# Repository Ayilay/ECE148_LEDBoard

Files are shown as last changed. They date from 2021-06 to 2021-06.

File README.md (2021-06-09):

# ECE148 LED Board

A PCB that arranges WS2812b individually addressable RGB LEDs in a rectangle underneath a Jetson Nano to give it a swank gaming-PC aesthetic.
Designed for [UCSD's ECE148 final project by Team 1, SP21](https://guitar.ucsd.edu/maeece148/index.php/2021SpringTeam1).

<p float="left">
  
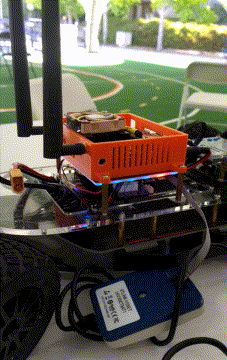
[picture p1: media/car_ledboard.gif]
  
</p>

## PCB Overview

This PCB was hastily designed and is not my finest work, due to the time constraint we faced and the
fact that turnaround times for PCBs take a few days unless one pays a small fortune.

The PCB was designed in [KiCad](https://www.kicad.org/).

**Features:**
- STM32 F103C8T6 Microcontroller
- 10-pin SWD debug header
- JST-PH power connector with MIC5219 3V3 LDO Regulator
- Power LED
- Input voltage range from 3.7 V to 5V
- 16x WS2812b (aka Neopixels) arranged in a rectangle

**Absent Features**

I mention these not to roast myself (well kinda), but as a disclaimer to those looking at my design 
as reference for theirs. As I mentioned, I was on a time crunch so I couldn't afford the time to make this
a good-quality PCB. The following features should be included in a good design:
- Reset Pushbutton
- Generic I/O Breakouts
- Generic Button/LED for testing
- Testpoints for signals/power

## Firmware Overview

I used Michael Tien's STM32 code for [driving WS2812B LEDs using SPI over DMA](https://michaeltien8901.github.io/stm32/2018/07/19/Using-STM32-SPI-For-LED-STRIP.html)

Porting his code was easy. I created a new STM32CubeMX project for an STM32F103C8T6 microcontroller,
enabled the SPI1 peripheral, added a DMA channel for it, and set the clock as he described.

Then I automatically generated the code, and copied over Tien's helper functions from his `main.c` file,
and it worked like a charm. His functions are very straightforward to use, so thanks!

## Programming the board

(TODO Pictures)

I dislike using clunky IDEs unless I absolutely have to (i.e. for large projects). So I setup my CubeMX
project to use a Makefile, and use `make` to compile the code. Then I use my STLink V3-SET debug adapter
to flash the code, though any ST-Link probe that has a mini 10-pin cable will do. A quick guide on how
I flash STM32 code is on my [CubeProgrammer TechNotes](https://github.com/Ayilay/dotfiles/blob/master/techNotes/CubeProgrammer.md)

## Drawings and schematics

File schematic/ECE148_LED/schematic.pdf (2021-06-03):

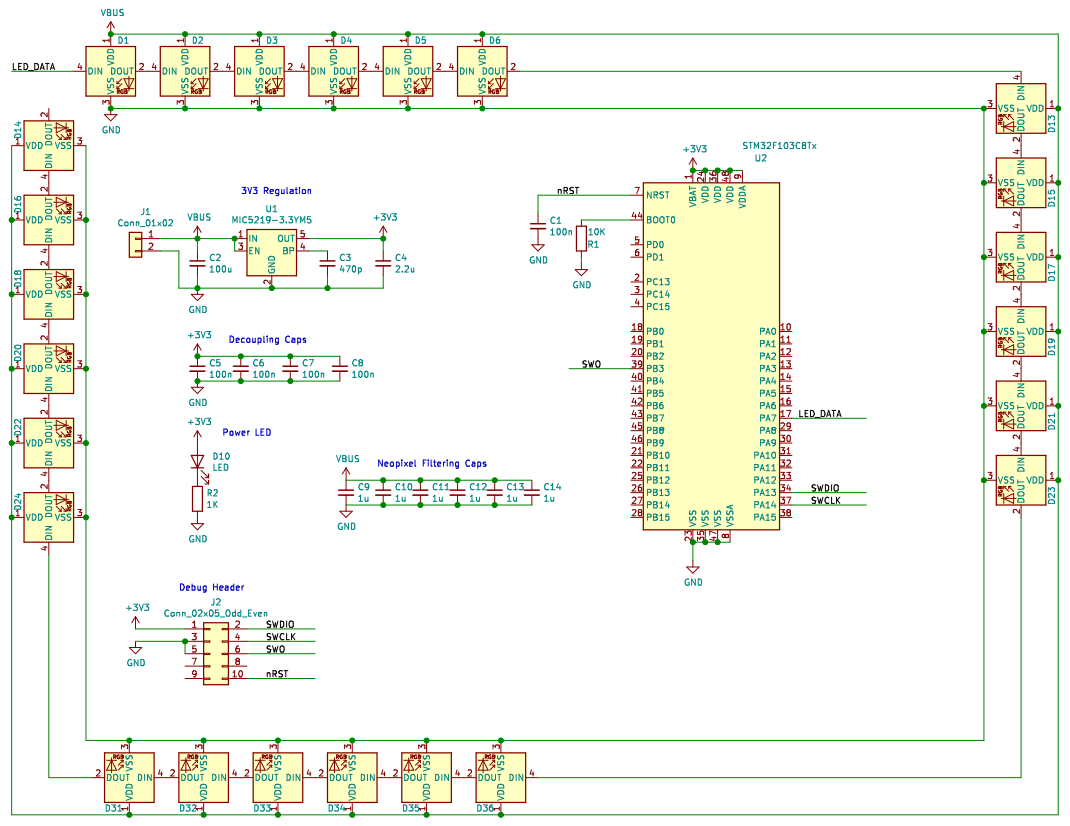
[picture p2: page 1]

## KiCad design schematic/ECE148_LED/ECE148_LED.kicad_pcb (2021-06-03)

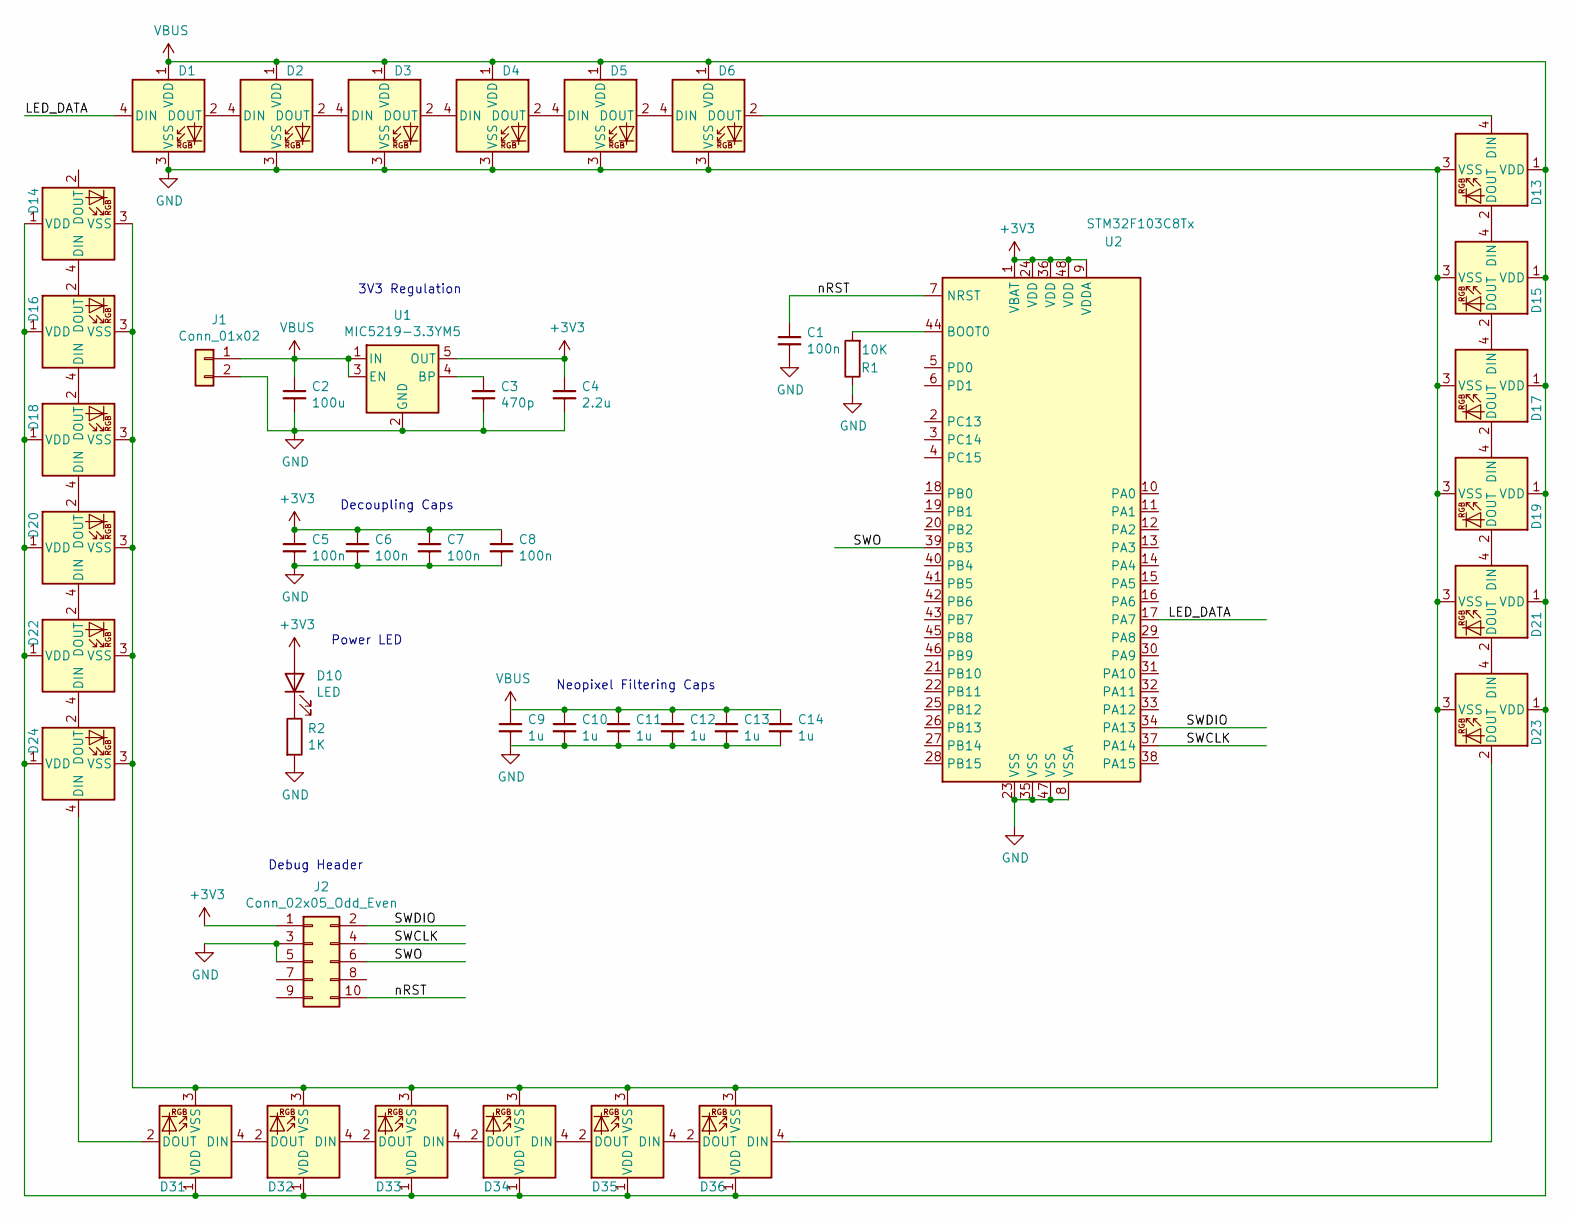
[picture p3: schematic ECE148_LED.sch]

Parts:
C1, C5, C6, C7, C8: 100n; C_0603_1608Metric
C2: 100u; CP_Radial_D5.0mm_P2.00mm
C3: 470p; C_0603_1608Metric
C4: 2.2u; C_0603_1608Metric
C9, C10, C11, C12, C13, C14: 1u; C_0603_1608Metric
D1, D2, D3, D4, D5, D6, D13, D14, D15, D16, D17, D18, D19, D20, D21, D22, D23, D24, D31, D32, D33, D34, D35, D36: WS2812B; LED_WS2812B_PLCC4_5.0x5.0mm_P3.2mm
D10: LED; LED_0805_2012Metric
J1: Conn_01x02; JST_PH_B2B-PH-K_1x02_P2.00mm_Vertical
J2: Conn_02x05_Odd_Even; PinHeader_2x05_P1.27mm_Vertical_SMD
R1: 10K; R_0603_1608Metric
R2: 1K; R_0603_1608Metric
U1: MIC5219-3.3YM5; SOT-23-5
U2: STM32F103C8Tx; LQFP-48_7x7mm_P0.5mm

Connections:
+3V3: C4.1, C5.1, C6.1, C7.1, C8.1, D10.2 (A), J2.1, U1.5 (OUT), U2.1 (VBAT), U2.9 (VDDA), U2.24 (VDD), U2.36 (VDD), U2.48 (VDD)
/LED_DATA: D1.4 (DIN), U2.17 (PA7)
/SWCLK: J2.4, U2.37 (PA14)
/SWDIO: J2.2, U2.34 (PA13)
/SWO: J2.6, U2.39 (PB3)
/nRST: C1.1, J2.10, U2.7 (NRST)
GND: C1.2, C2.2, C3.2, C4.2, C5.2, C6.2, C7.2, C8.2, C9.2, C10.2, C11.2, C12.2, C13.2, C14.2, D1.3 (VSS), D2.3 (VSS), D3.3 (VSS), D4.3 (VSS), D5.3 (VSS), D6.3 (VSS), D13.3 (VSS), D14.3 (VSS), D15.3 (VSS), D16.3 (VSS), D17.3 (VSS), D18.3 (VSS), D19.3 (VSS), D20.3 (VSS), D21.3 (VSS), D22.3 (VSS), D23.3 (VSS), D24.3 (VSS), D31.3 (VSS), D32.3 (VSS), D33.3 (VSS), D34.3 (VSS), D35.3 (VSS), D36.3 (VSS), J1.2, J2.3, J2.5, R1.1, R2.2, U1.2 (GND), U2.8 (VSSA), U2.23 (VSS), U2.35 (VSS), U2.47 (VSS)
unnamed: C3.1, U1.4 (BP)
unnamed: D1.2 (DOUT), D2.4 (DIN)
unnamed: D2.2 (DOUT), D3.4 (DIN)
unnamed: D3.2 (DOUT), D4.4 (DIN)
unnamed: D4.2 (DOUT), D5.4 (DIN)
unnamed: D5.2 (DOUT), D6.4 (DIN)
unnamed: D10.1 (K), R2.1
unnamed: D13.2 (DOUT), D15.4 (DIN)
unnamed: D6.2 (DOUT), D13.4 (DIN)
unnamed: D14.4 (DIN), D16.2 (DOUT)
unnamed: D15.2 (DOUT), D17.4 (DIN)
unnamed: D16.4 (DIN), D18.2 (DOUT)
unnamed: D17.2 (DOUT), D19.4 (DIN)
unnamed: D18.4 (DIN), D20.2 (DOUT)
unnamed: D19.2 (DOUT), D21.4 (DIN)
unnamed: D20.4 (DIN), D22.2 (DOUT)
unnamed: D21.2 (DOUT), D23.4 (DIN)
unnamed: D22.4 (DIN), D24.2 (DOUT)
unnamed: D23.2 (DOUT), D36.4 (DIN)
unnamed: D24.4 (DIN), D31.2 (DOUT)
unnamed: D31.4 (DIN), D32.2 (DOUT)
unnamed: D32.4 (DIN), D33.2 (DOUT)
unnamed: D33.4 (DIN), D34.2 (DOUT)
unnamed: D34.4 (DIN), D35.2 (DOUT)
unnamed: D35.4 (DIN), D36.2 (DOUT)
unnamed: R1.2, U2.44 (BOOT0)
VBUS: C2.1, C9.1, C10.1, C11.1, C12.1, C13.1, C14.1, D1.1 (VDD), D2.1 (VDD), D3.1 (VDD), D4.1 (VDD), D5.1 (VDD), D6.1 (VDD), D13.1 (VDD), D14.1 (VDD), D15.1 (VDD), D16.1 (VDD), D17.1 (VDD), D18.1 (VDD), D19.1 (VDD), D20.1 (VDD), D21.1 (VDD), D22.1 (VDD), D23.1 (VDD), D24.1 (VDD), D31.1 (VDD), D32.1 (VDD), D33.1 (VDD), D34.1 (VDD), D35.1 (VDD), D36.1 (VDD), J1.1, U1.1 (IN), U1.3 (EN)

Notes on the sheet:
Decoupling Caps
3V3 Regulation
Power LED
Debug Header
Neopixel Filtering Caps

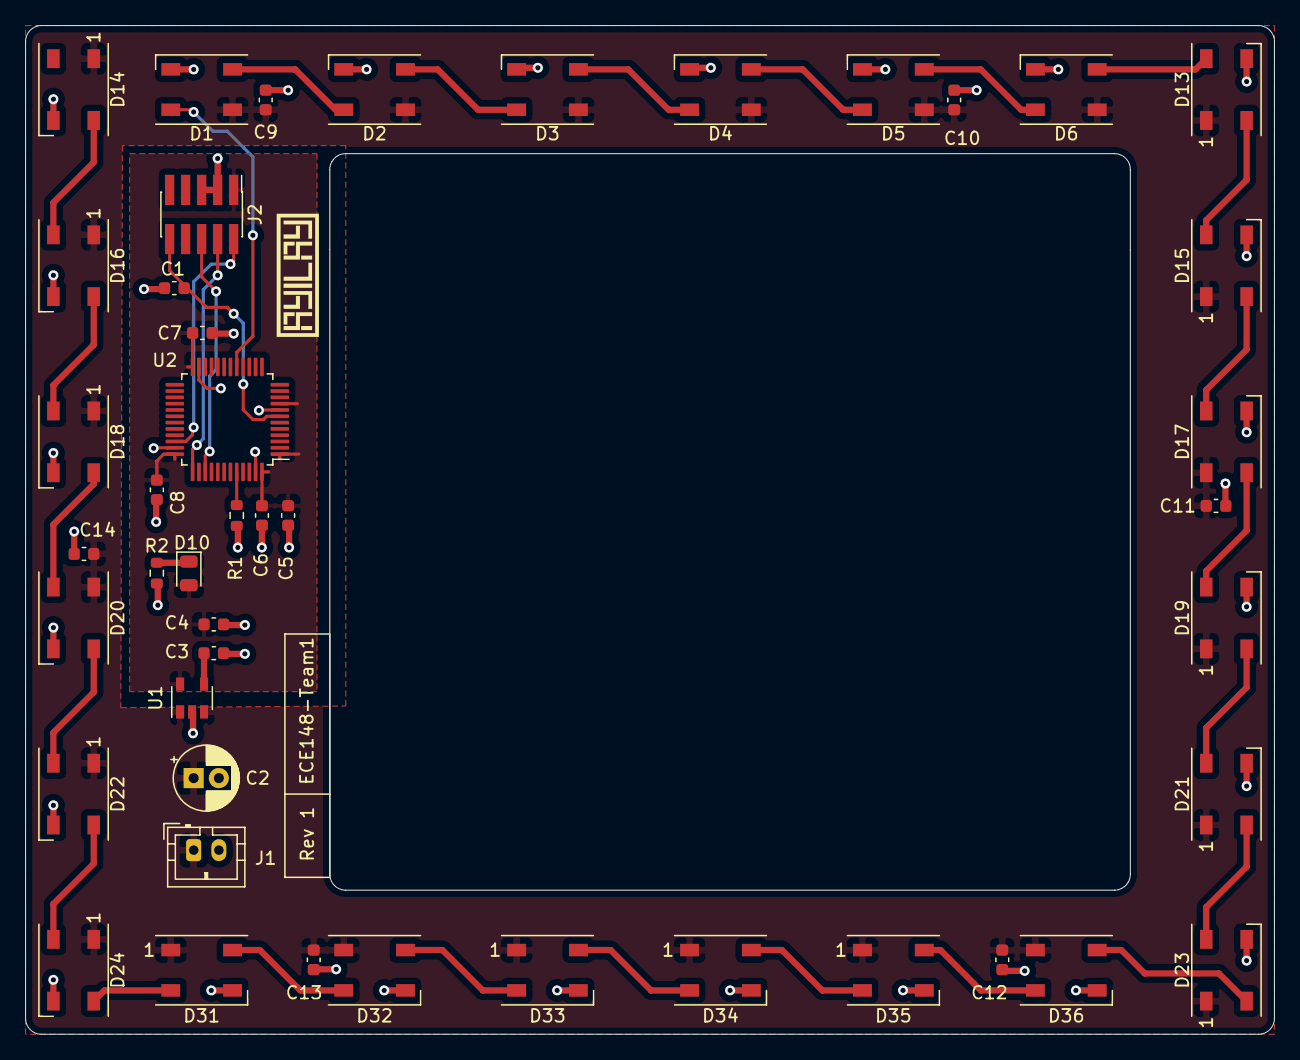
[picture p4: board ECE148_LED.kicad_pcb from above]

Board: 2 copper layers, 99.1 x 80.0 mm, 45 parts (0 on the bottom side), 34 nets.

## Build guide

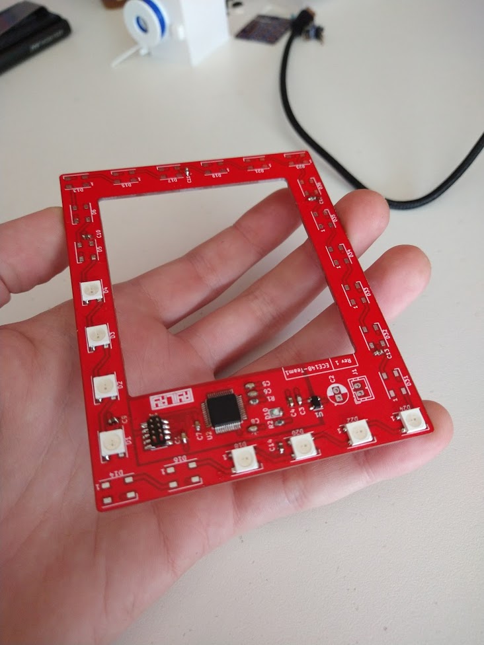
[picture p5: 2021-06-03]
media/pcb_solder_prog.jpg

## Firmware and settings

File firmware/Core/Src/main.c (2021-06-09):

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
/* Includes ------------------------------------------------------------------*/
#include "main.h"

/* USER CODE BEGIN PD */
#define LED_DELAY (1400 / LED_NO)
//#define LED_DELAY (3000 / LED_NO)
/* USER CODE END PD */

/* USER CODE BEGIN PM */
void doPattern1();
void doPattern2();
void doPattern3();

/* USER CODE END PM */

SPI_HandleTypeDef hspi1;
DMA_HandleTypeDef hdma_spi1_tx;

void SystemClock_Config(void);
static void MX_GPIO_Init(void);
static void MX_DMA_Init(void);
static void MX_SPI1_Init(void);
/* USER CODE BEGIN 0 */

#define LED_NO    24
#define LED_BUFFER_LENGTH (LED_NO*12)

const uint8_t leddata[256*4] = { // size = 256 * 3
  0X44 , 0X44 , 0X44 , 0X44 , // 0
  0X44 , 0X44 , 0X44 , 0X47 , // 1
  0X44 , 0X44 , 0X44 , 0X74 , // 2
  0X44 , 0X44 , 0X44 , 0X77 , // 3
  0X44 , 0X44 , 0X47 , 0X44 , // 4
  0X44 , 0X44 , 0X47 , 0X47 , // 5
  0X44 , 0X44 , 0X47 , 0X74 , // 6
  0X44 , 0X44 , 0X47 , 0X77 , // 7
  0X44 , 0X44 , 0X74 , 0X44 , // 8
  0X44 , 0X44 , 0X74 , 0X47 , // 9
  0X44 , 0X44 , 0X74 , 0X74 , // 10
  0X44 , 0X44 , 0X74 , 0X77 , // 11
  0X44 , 0X44 , 0X77 , 0X44 , // 12
  0X44 , 0X44 , 0X77 , 0X47 , // 13
  0X44 , 0X44 , 0X77 , 0X74 , // 14
  0X44 , 0X44 , 0X77 , 0X77 , // 15
  0X44 , 0X47 , 0X44 , 0X44 , // 16
  0X44 , 0X47 , 0X44 , 0X47 , // 17
  0X44 , 0X47 , 0X44 , 0X74 , // 18
  0X44 , 0X47 , 0X44 , 0X77 , // 19
  0X44 , 0X47 , 0X47 , 0X44 , // 20
  0X44 , 0X47 , 0X47 , 0X47 , // 21
  0X44 , 0X47 , 0X47 , 0X74 , // 22
  0X44 , 0X47 , 0X47 , 0X77 , // 23
  0X44 , 0X47 , 0X74 , 0X44 , // 24
  0X44 , 0X47 , 0X74 , 0X47 , // 25
  0X44 , 0X47 , 0X74 , 0X74 , // 26
  0X44 , 0X47 , 0X74 , 0X77 , // 27
  0X44 , 0X47 , 0X77 , 0X44 , // 28
  0X44 , 0X47 , 0X77 , 0X47 , // 29
  0X44 , 0X47 , 0X77 , 0X74 , // 30
  0X44 , 0X47 , 0X77 , 0X77 , // 31
  0X44 , 0X74 , 0X44 , 0X44 , // 32
  0X44 , 0X74 , 0X44 , 0X47 , // 33
  0X44 , 0X74 , 0X44 , 0X74 , // 34
  0X44 , 0X74 , 0X44 , 0X77 , // 35
  0X44 , 0X74 , 0X47 , 0X44 , // 36
  0X44 , 0X74 , 0X47 , 0X47 , // 37
  0X44 , 0X74 , 0X47 , 0X74 , // 38
  0X44 , 0X74 , 0X47 , 0X77 , // 39
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
};

uint8_t ws_buffer[LED_BUFFER_LENGTH];

void encode_byte(uint8_t data, int16_t buffer_index) {
  int index = data * 4;
  ws_buffer[buffer_index++] = leddata[index++];
  ws_buffer[buffer_index++] = leddata[index++];
  ws_buffer[buffer_index++] = leddata[index++];
  ws_buffer[buffer_index++] = leddata[index++];
}

void generate_ws_buffer(uint8_t RData, uint8_t GData, uint8_t BData, int16_t led_no) {
  //ws2812b
  //G--R--B
  //MSB first
  int offset = led_no * 12;
  encode_byte( GData, offset );
  encode_byte( RData, offset+4 );
  encode_byte( BData, offset+8 );
}

void Send_2812(void)
{
  HAL_SPI_Transmit_DMA(&hspi1, ws_buffer, LED_BUFFER_LENGTH);

  // LMAO this defeats the point of DMA?
  while(__HAL_SPI_GET_FLAG(&hspi1, SPI_FLAG_BSY ));
}

void setAllPixelColor(uint8_t r, uint8_t g, uint8_t b)
{
  int i;
  for(i=0;i< LED_NO;i++) {
    generate_ws_buffer( r, g, b, i );
  }
  Send_2812();
}

void setPixelColor(uint16_t n, uint8_t r, uint8_t g, uint8_t b)
{
  generate_ws_buffer( r, g, b, n );
  Send_2812();
}
/**
 * initialize MOSI pin to LOW.  Without this, first time transmit for first LED might be wrong.
 *
 */
void initLEDMOSI(void)
{
  uint8_t buffer0[2] = { 0, 0 };
  HAL_SPI_Transmit(&hspi1, buffer0, 1, 100 );
}

/* USER CODE END 0 */

/**
 * @brief  The application entry point.
 * @retval int
 */
int main(void)
{
  /* MCU Configuration--------------------------------------------------------*/

  /* Reset of all peripherals, Initializes the Flash interface and the Systick. */
  HAL_Init();

  /* Configure the system clock */
  SystemClock_Config();

  /* Initialize all configured peripherals */
  MX_GPIO_Init();
  MX_DMA_Init();
  MX_SPI1_Init();
  /* Infinite loop */
  /* USER CODE BEGIN WHILE */
  initLEDMOSI();
  while (1)
  {
    /* USER CODE END WHILE */

    /* USER CODE BEGIN 3 */
    doPattern3();

  }
  /* USER CODE END 3 */
}

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
/* USER CODE BEGIN 4 */

void doPattern1() {
  // red
  int i;
  for ( i = 0; i < LED_NO; i++) {
    setPixelColor( i, 50, 0, 0 );
    HAL_Delay(LED_DELAY);
  }
  // green
  for ( i = 0; i < LED_NO; i++) {
    setPixelColor( i, 0, 50, 0 );
    HAL_Delay(LED_DELAY);
  }
  // blue
  for ( i = 0; i < LED_NO; i++) {
    setPixelColor( i, 0, 0, 50 );
    HAL_Delay(LED_DELAY);
  }
}

void doPattern2() {
  static uint16_t ledChase = 0;

  for ( int i = 0; i < LED_NO; i++) {
    generate_ws_buffer(10, 30, 0, i );
  }
  generate_ws_buffer( 60, 30,  0, ledChase );
  generate_ws_buffer( 60,  0,  0, (ledChase +   (LED_NO/4)) % LED_NO);
  generate_ws_buffer( 60, 30,  0, (ledChase + 2*(LED_NO/4)) % LED_NO);
  generate_ws_buffer( 60,  0,  0, (ledChase + 3*(LED_NO/4)) % LED_NO);

  ledChase = (ledChase + 1) % LED_NO;
  Send_2812();
  HAL_Delay(LED_DELAY);
}

#define ABS(N) ((N<0)?(-N):(N))

void doPattern3() {
  //uint16_t ledChase = 0;

  #define lin1_offset ( 6)
  #define lin2_offset (23)
  #define lin3_offset ( 2)
  #define lin4_offset ( 5)
  #define SIDE_LEN    (6)

  for (int ledChase = 0; ledChase < SIDE_LEN; ledChase ++) {
    for ( int i = 0; i < LED_NO; i++) {
      generate_ws_buffer( 0, 20, 40, i );
    }
    generate_ws_buffer(120, 60,  0,  ledChase + lin1_offset );
    generate_ws_buffer(120, 60,  0, -ledChase + lin2_offset );

    Send_2812();
    HAL_Delay(LED_DELAY);
  }
  for (int ledChase = SIDE_LEN-1; ledChase >= 0; ledChase --) {
    for ( int i = 0; i < LED_NO; i++) {
      generate_ws_buffer( 0, 20, 40, i );
    }
    generate_ws_buffer(120, 60,  0,  ledChase + lin1_offset );
    generate_ws_buffer(120, 60,  0, -ledChase + lin2_offset );

    Send_2812();
    HAL_Delay(LED_DELAY);
  }

  //ledChase = (ledChase + 1) % SIDE_LEN;


}

/* USER CODE END 4 */
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


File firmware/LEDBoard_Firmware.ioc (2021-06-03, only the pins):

Mcu.UserName=STM32F103C8Tx
PA13.Signal=SYS_JTMS-SWDIO
PA14.Signal=SYS_JTCK-SWCLK
PA5.Signal=SPI1_SCK
PA7.Signal=SPI1_MOSI
PB3.Signal=SYS_JTDO-TRACESWO

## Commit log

2021-06-03 Added picture of PCB
2021-06-03 Added schematic files
    [ECE148_LED-B_Cu.gbl, ECE148_LED-B_Mask.gbs, ECE148_LED-B_Paste.gbp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]
2021-06-03 Added KiCad credits to README
2021-06-04 Fixed dumb typo, and new compiled binaries
    [main.c]
2021-06-08 Added GIF of LED Board working
2021-06-08 Made LED Board GIF larger
2021-06-08 Updated LED pattern to be 4 chasing LEDs around the ring
2021-06-08 Added 3rd LED Pattern, Linear Chasing
2021-06-09 Added gif of LEDBoard mounted on car
2021-06-09 Fix gif of car ledboard

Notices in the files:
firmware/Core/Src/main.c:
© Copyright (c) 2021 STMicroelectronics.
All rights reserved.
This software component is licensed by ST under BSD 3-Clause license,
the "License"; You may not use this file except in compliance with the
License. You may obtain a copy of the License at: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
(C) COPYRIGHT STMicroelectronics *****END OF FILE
